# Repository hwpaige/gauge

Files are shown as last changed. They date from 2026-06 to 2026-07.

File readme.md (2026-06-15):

# CHT Gauge

A twin cylinder head temperature (CHT) gauge running on a Banana Pi M4 Zero, displayed on a 1.3" round SPI LCD. Designed to look like a dark-themed aircraft avionics instrument — two filled-arc gauges side by side, one per cylinder, with colour-coded temperature zones and a D-DIN digital readout.

---

## Hardware

| Component | Part |
|---|---|
| SBC | Banana Pi M4 Zero (Allwinner H618, quad-core A53) |
| Display | Pimoroni 1.3" Round SPI Colour LCD (ST7789, 240×240) — PIM570 |
| Thermocouple | MAX31855 or MAX6675 breakout (×2, one per cylinder) |
| OS | Armbian Debian Trixie Minimal |

**Important**: The kernel must provide `/dev/fb0` for the ST7789 (see "Kernel framebuffer driver" below). The Python app no longer drives the display directly.

---

## Wiring

### Display → BPI M4 Zero 40-pin header

The kernel framebuffer overlay (not the Python app) owns the pins. Example mapping used by current overlays/driver code (confirm against your .dts):

| Display Pin | Signal | BPI Header Pin | Notes (Allwinner) |
|---|---|---|---|
| VCC | 3.3V | Pin 1 | |
| GND | GND | Pin 6 | |
| CS | SPI1 CS0 (PH5)  | Pin 24 | |
| SCK | SPI1 SCLK (PH6) | Pin 23 | |
| MOSI | SPI1 MOSI (PH7) | Pin 19 | |
| DC | PI16 | Pin 18 | (offset 272) |
| RST | PC2 | Pin 22 | (offset 66) |
| (BL) | (backlight) | (Pin 35) | Tie to 3.3V (Pin 1) if not software-controlled |

> Backlight: tie BL directly to 3.3V for always-on (recommended for gauge). The kernel panel driver typically handles reset/DC in its DT.

### Thermocouple (MAX31855 / MAX6675) — to be wired

Thermocouples share the SPI bus with the display using separate CS pins. Wiring and sensor code will be added in a future update.

---

## Project Structure

```
cht-gauge/
├── setup.sh          # One-shot bootstrap — run on fresh Armbian flash
├── gauge.py          # Main application (uses kernel /dev/fb0)
├── run.sh            # Launch script
├── test_display.py   # Legacy userspace test (may fail once kernel owns display)
├── pin_test.py       # Dev tool for probing GPIOs/SPI (kernel pins will be busy)
├── driver.py         # Legacy userspace ST7789 driver (kept for reference)
├── .gitignore
└── fonts/
    └── README.md     # Fonts are downloaded by setup.sh, not committed to repo
```

---

## Fresh Install Instructions

### 1. Flash Armbian

Download **Armbian Debian Trixie Minimal** for BPI M4 Zero:
```
https://dl.armbian.com/bananapim4zero/Trixie_current_minimal
```

Flash with [Armbian Imager](https://imager.armbian.com) or Balena Etcher. Pre-configure WiFi credentials in the imager before flashing.

### 2. SSH in

Find the device IP via your router's DHCP client list, then:

```bash
ssh root@<ip-address>
# Default password: 1234 (you'll be prompted to change it)
```

### 3. Run setup

```bash
wget https://raw.githubusercontent.com/hwpaige/gauge/master/setup.sh
bash setup.sh
```

The script will:
- Set the hostname to `moto` (SSH via `root@moto.local` after reboot)
- Enable SPI in `/boot/armbianEnv.txt`
- Install all system and Python dependencies
- Clone this repo to `/root/gauge`
- Download the D-DIN font
- Create a Python virtual environment and install packages
- Prompt to reboot

After reboot, SSH back in with:

```bash
ssh root@moto.local
```

### 4. Test the display

Once the kernel framebuffer driver is active (see below), the display is the system primary framebuffer. A basic test that the fb is working:

```bash
cat /dev/urandom > /dev/fb0   # noise on screen; Ctrl-C to stop
```

Or (inside venv):

```bash
cd /root/gauge
source venv/bin/activate
python3 -c "
import pygame, os
os.environ['SDL_VIDEODRIVER']='fbcon'; os.environ['SDL_FBDEV']='/dev/fb0'
pygame.init()
s = pygame.display.set_mode((240,280))
s.fill((255,0,0)); pygame.display.flip()
input('red fb - press enter'); pygame.quit()
"
```

(If the legacy `test_display.py` using the Python `st7789` package fails with EBUSY, that is expected once the kernel driver owns the pins — it is no longer needed.)

See "Kernel framebuffer driver" section for how the display becomes `/dev/fb0`.

### 5. Run the gauge

```bash
/root/gauge/run.sh
```

(Or manually: `cd /root/gauge && source venv/bin/activate && python3 gauge.py`)

**Important:** Because the kernel is now driving the round display as the primary framebuffer/console, you must run the gauge while on the **actual Linux console** that the display is attached to (not over SSH in most cases).

- Easiest for testing: Plug a USB keyboard into the Banana Pi. The round display should be showing the login prompt. Login directly there as root and run the command on that console.
- SSH sessions often produce `pygame.error: fbcon not available` because the SDL fbcon driver needs a real virtual terminal context.
- For production (recommended): use the included `gauge.service` so it starts automatically on boot and takes over the round display console. No keyboard or SSH run needed after setup.

### Auto-start via systemd (recommended)

From SSH on the Pi:

```bash
cd /root/gauge
git pull   # get the latest gauge.service if you haven't already

sudo cp gauge.service /etc/systemd/system/
sudo systemctl daemon-reload
sudo systemctl enable --now gauge.service

# Optional: stop the default getty so the gauge owns the console cleanly
# (the service tries to chvt to tty1)
sudo systemctl stop getty@tty1.service
sudo systemctl disable getty@tty1.service
```

Check status:

```bash
systemctl status gauge.service
journalctl -u gauge.service -f
```

To stop it temporarily and get a console back:

```bash
sudo systemctl stop gauge.service
sudo chvt 1
# or reboot
```

The service is configured to restart on failure and attaches to the framebuffer console.

See the on-screen error message in the new gauge.py for more details and a quick kernel-fb test command that *does* work over SSH.

---

## Application

`gauge.py` renders two CHT gauges using **pygame** directed at the Linux framebuffer (`/dev/fb0`) via SDL fbcon — no desktop environment required.

The kernel (via a DT overlay for the ST7789 panel, typically exposing `fb_st7789v` or equivalent) must own the display and expose `/dev/fb0` (240×280 logical with the round 240×240 visible area at y=40). The Python code now renders offscreen and writes raw RGB565 frames directly to `/dev/fb0`. This completely avoids SDL's fbcon video driver (which is frequently missing/broken in packaged SDL2 on Armbian) while still benefiting from the kernel's smooth panel handling.

The old userspace Python ST7789 + gpiod + spidev driver path has been removed from the main app (it conflicts with "Device or resource busy" once the kernel claims the pins).

### Gauge design

- **Black background** with slight blue tint
- **270° filled arc** sweep per gauge
- **Colour zones:**
  - Green — 0–60% of range (normal)
  - Amber — 60–85% (caution)
  - Red — 85–100% (danger)
- **Tick marks** — major at 0%, 50%, 100%; minor every 10%
- **Digital readout** in the arc colour at the gauge centre
- **D-DIN font** throughout — industrial/avionics aesthetic
- **Centre divider** with "CYLINDER HEAD TEMP" header

### Temperature ranges

Min/max values are set per-gauge in `gauge.py`:

```python
draw_gauge(screen, LEFT_CENTER,  cht1, 0, 300, "CYL 1", font, small_font)
draw_gauge(screen, RIGHT_CENTER, cht2, 0, 300, "CYL 2", font, small_font)
```

Change `0` and `300` to match your engine's actual operating range.

### Sensor reads

The `read_cht(channel)` function in `gauge.py` currently returns simulated sine-wave values for testing. Replace it with real MAX31855/MAX6675 SPI reads when the thermocouple hardware is wired up.

---

## Dependencies

### System packages

Installed by `setup.sh`:

- `gcc`, `build-essential` — for compiling Python C extensions
- `python3-venv`, `python3-dev`, `python3-pip`
- `git`, `wget`, `unzip`
- `avahi-daemon` — enables `.local` mDNS hostname resolution
- `libsdl2-dev`, `libsdl2-image-dev`, `libsdl2-ttf-dev` — pygame display

### Python packages (runtime)

Installed into `/root/gauge/venv`:

- `pygame` — rendering engine (fbcon targeting kernel `/dev/fb0`)

`st7789`, `pillow`, `spidev`, `gpiod`, `numpy` are also pulled in for the legacy test scripts only.

---

## Kernel framebuffer driver (required)

After the initial `setup.sh` (which only enables spidev), you must make the ST7789 the kernel's primary framebuffer (`/dev/fb0`) so that:

- The kernel owns DC, RST, and the SPI pins (your app will no longer get "Device or resource busy").
- Updates are smooth / tear-free (as you observed after the reboot that made the round display primary).

Typical steps (edit as root):

1. Create a device-tree overlay (example name `st7789-fb.dts`) in `/boot/overlay-user/` (or `/boot/dtb/overlay/` depending on Armbian version). A minimal overlay declares the spi bus + panel compatible (sitronix,st7789v or fbtft), with the correct GPIOs for your board (DC=PI16/272 on pin 18, RST=PC2/66 on pin 22, SPI1 on PH5-8), width/height, and any rotation/x/y offsets the round visible area needs (the gauge code assumes a 240×280 fb with visible content at y=40).

2. Compile it:
   ```
   armbian-add-overlay /boot/overlay-user/st7789-fb.dts
   ```
   (or `dtc -@ -I dts -O dtb -o /boot/dtb/allwinner/overlay/st7789-fb.dtbo ...` and add to user_overlays).

3. Edit `/boot/armbianEnv.txt`:
   ```
   overlays=... spi-spidev   # or remove spidev if the panel driver claims the bus exclusively
   user_overlays=st7789-fb
   # extraargs or param_ lines as required by your overlay (bus num, speed, etc.)
   ```

4. Reboot.

5. Verify:
   ```
   ls -l /dev/fb0
   fbset   # or cat /sys/class/graphics/fb0/virtual_size  (expect something like 240x280)
   ```

Once `/dev/fb0` is the round display, `python3 gauge.py` (or `run.sh`) will use it directly and be super smooth.

If you have a working overlay .dts that matches the Pimoroni 1.3" + BPI M4 Zero pinout (SPI1, offsets 272/66, y_off=40), contribute it!

The gauge code hard-codes the 240×280 / y=40 layout that the kernel driver must expose for the round 240×240 visible panel.

---

## Roadmap

- [ ] Wire and integrate MAX31855 thermocouple reads
- [ ] Add configurable temperature range and alarm thresholds
- [ ] Auto-launch gauge on boot via systemd service
- [ ] Add EGT (exhaust gas temperature) display mode

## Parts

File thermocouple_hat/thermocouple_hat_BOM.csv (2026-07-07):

Designator | Comment | Footprint | Qty
C1,C2,C3,C4,C5,C6,C7,C8,C9,C10,C11,C12,C13,C14 | 100n | Capacitor_SMD:C_0402_1005Metric | 14
D1,D2,D3,D4 | PRTR5V0U2X | Package_TO_SOT_SMD:SOT-143 | 4
J1 | GPIO | Connector_PinSocket_2.54mm:PinSocket_2x20_P2.54mm_Vertical | 1
J2 | Waveshare_1.28in_Touch | Connector_JST:JST_GH_BM13B-GHS-TBT_1x13-1MP_P1.25mm_Vertical | 1
J3 | TC1 | TerminalBlock_Phoenix:TerminalBlock_Phoenix_MPT-0,5-2-2.54_1x02_P2.54mm_Horizontal | 1
J4 | TC2 | TerminalBlock_Phoenix:TerminalBlock_Phoenix_MPT-0,5-2-2.54_1x02_P2.54mm_Horizontal | 1
J5 | TC3 | TerminalBlock_Phoenix:TerminalBlock_Phoenix_MPT-0,5-2-2.54_1x02_P2.54mm_Horizontal | 1
J6 | TC4 | TerminalBlock_Phoenix:TerminalBlock_Phoenix_MPT-0,5-2-2.54_1x02_P2.54mm_Horizontal | 1
LED5 | LED_GREEN | LED_SMD:LED_0603_1608Metric | 1
R1,R2 | 3.9k | Resistor_SMD:R_0402_1005Metric | 2
R3,R4,R17,R18 | 100k | Resistor_SMD:R_0402_1005Metric | 4
R5,R6,R7,R8,R9,R10,R11,R12 | 100 | Resistor_SMD:R_0402_1005Metric | 8
R13,R14,R15,R16 | 10k | Resistor_SMD:R_0402_1005Metric | 4
R23 | 330 | Resistor_SMD:R_0402_1005Metric | 1
R24,R25 | 4.7k | Resistor_SMD:R_0402_1005Metric | 2
U1 | CAT24C256 | Package_SO:SOIC-8_3.9x4.9mm_P1.27mm | 1
U2,U3,U4,U5 | MAX31856 | Package_SO:TSSOP-14_4.4x5mm_P0.65mm | 4
U6 | DS3231MZ | Package_SO:SOIC-8_3.9x4.9mm_P1.27mm | 1

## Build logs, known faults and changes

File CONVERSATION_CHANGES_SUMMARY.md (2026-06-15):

# Banana Pi CHT Gauge - Conversation Changes Summary

**Date**: June 2026 (conversation spanned ~June 14-15)  
**Project**: `gauge` - Twin cylinder head temperature (CHT) gauge on Banana Pi M4 Zero with 1.3" round ST7789 SPI display.  
**Goal of this conversation**: Fix the app after the kernel took over the display as the primary framebuffer.

## Background & Original Problem

- After a reboot, the Banana Pi was using the round display as the **primary display** via the kernel framebuffer driver (`fb_st7789v` or equivalent).
- This produced "super smooth" output with no flickering (the kernel driver handled SPI/panel timing well).
- The existing `gauge.py` (and `driver.py`) used a **userspace ST7789 driver** (`gpiod.request_lines` for DC/RST + `spidev`).
- This caused: `OSError: [Errno 16] Device or resource busy` because the kernel had already claimed the GPIO pins and SPI bus.
- The local workspace had **uncommitted changes** switching to kernel `/dev/fb0` + `pygame` + `fbcon`, but the Pi's `git pull` saw an old version (and later hit an untracked `pin_test.py` conflict).

The root cause: The project had evolved to rely on the **kernel owning the display** for smoothness, but the code and deployment weren't fully updated for that reality.

## Major Architectural Shift

**From**: Userspace pixel pushing (Pygame offscreen → custom ST7789 class → SPI via `spidev` + GPIO via `gpiod`).

**To**: Kernel framebuffer direct write.
- Pygame renders offscreen only (using `SDL_VIDEODRIVER=dummy`).
- At the end of each frame, convert the 240×280 surface to raw **RGB565** bytes.
- Write directly to `/dev/fb0` (via `mmap` for efficiency).
- This lets the **kernel driver** handle all the panel timing, SPI, and refresh — matching the smooth behavior the user observed with the console.

This also eliminated the GPIO "busy" conflict.

## Key Code Changes (gauge.py)

- Removed reliance on `driver.py` / `ST7789` class and `gpiod`/`spidev` for the main app.
- Added `os.environ` setup early (before `import pygame`).
- New helper: `_surface_to_fb565(surface)` — converts Pygame surface to RGB565 bytes.
  - Prefers `numpy` for speed (when available).
  - Pure-Python fallback.
  - Includes **byte swap** to match the format the original userspace driver (and kernel fb) expected:
    ```python
    rgb565 = ((r & 0xF8) << 8) | ((g & 0xFC) << 3) | (b >> 3)
    rgb565 = ((rgb565 >> 8) | ((rgb565 & 0xFF) << 8))  # byte swap
    ```
- Switched to offscreen `full_fb` surface (240×280) + blitting the 240×240 gauge at `y=FB_Y_OFF=40`.
- Direct write path:
  - `open('/dev/fb0', 'r+b')` + `mmap.mmap(...)`
  - `fb_map[:] = buf; fb_map.flush()`
- Added `FBIO_WAITFORVSYNC` ioctl (best-effort) after writes to improve timing and reduce tearing (to better match the kernel console's smoothness).
- **Startup reliability fixes**:
  - Immediate **solid red test pattern** (for 1.5s) on startup for visibility debugging.
  - Explicit first real gauge frame written before the main loop.
  - Prints to journal for diagnostics.
- Debug prints: `SDL_VIDEODRIVER`, framebuffer checks, "First real gauge frame written", etc.
- Graceful cleanup of mmap/fd on exit.
- Event loop (Q to quit) preserved for testing.

## Systemd Service (new file: gauge.service)

- Created `gauge.service` for auto-launch on boot.
- Uses `Environment=SDL_VIDEODRIVER=dummy` + direct `/dev/fb0` write.
- `ExecStartPre` steps:
  - `chvt 1`
  - Disable cursor blink
  - Stop interfering gettys (`getty@tty1`, serial gettys, etc.)
- `Restart=always`, `StandardOutput=journal` / `StandardError=journal` (prevents error text from being painted onto the framebuffer as "terminal" garbage).
- TTY-related options retained for the console context.
- Installation instructions added to README.

High CPU time seen in early journals was from long crash/restart loops on the old fbcon code.

## Documentation & Supporting Files

- **readme.md**:
  - Major rewrite of "Kernel framebuffer driver (required)" section.
  - Updated wiring table (correct BPI M4 Zero pins: SPI1 on PH5–PH8, DC=PI16/pin18, RST=PC2/pin22).
  - New "Auto-start via systemd" subsection with concrete commands.
  - Updated install/test/run instructions (emphasize kernel fb, SSH vs local console).
  - Explained why userspace ST7789 + gpiod/pillow/etc. are now legacy.
- **setup.sh**: Added warnings about needing the kernel ST7789/fb overlay (in addition to spi-spidev). Updated final notes and test instructions.
- **run.sh**: Updated comment to reflect direct fb path.
- **requirements.txt**: Clarified that only `pygame` is runtime-required; others are for legacy tools.
- **test_display.py**: Marked as legacy (will fail with EBUSY once kernel owns pins).
- **pin_test.py**: Committed (was previously untracked in some clones); contains kernel-owned pin warnings.
- Added `CONVERSATION_CHANGES_SUMMARY.md` (this file) for future reference.

## Debugging Journey (Key Failures & Fixes)

1. **EBUSY on gpiod** → Realized kernel now owns display → switched to fb path + pushed commits.
2. **Untracked `pin_test.py` blocking pull** → User `mv` + `git pull`.
3. **`fbcon not available`** (over SSH) → Explained console vs. SSH context. Created systemd service as long-term solution (no keyboard required).
4. **"Only showing in red"** → RGB565 byte order was wrong. Matched original `driver.py` conversion (byte swap).
5. **Blank screen after mmap/vsync** → Vsync ioctl could block before first write. Added:
   - Immediate red test pattern.
   - Explicit first real frame write + prints.
   - Moved vsync *after* write.
6. **High CPU in journal** → Artifact of long restart loop on broken code; fixed by stable direct-write path.

User observation that helped: "When the kernel was the display output, the CLI was super smooth including the blinking cursor (no rapid refresh)." This drove the mmap + vsync improvements to emulate kernel fbcon timing.

## Current Recommended Workflow (as of end of conversation)

1. Kernel DT overlay must expose the round ST7789 as `/dev/fb0` (240×280 logical, visible at y=40).
2. `git pull` on Pi.
3. Install/restart service:
   ```bash
   sudo cp gauge.service /etc/systemd/system/
   sudo systemctl daemon-reload
   sudo systemctl enable --now gauge.service
   # Optional: stop getty
   sudo systemctl stop getty@tty1.service
   sudo systemctl disable getty@tty1.service
   ```
4. Journal for logs: `journalctl -u gauge.service -f`
5. Temporary clean console: `sudo systemctl stop gauge.service && sudo chvt 1`
6. Quick hardware test (works over SSH): `cat /dev/urandom > /dev/fb0` (Ctrl-C after 1-2s). Should show noise if `/dev/fb0` is the round panel.

## Files Changed / Added

- `gauge.py` (major rewrite)
- `gauge.service` (new)
- `readme.md`
- `setup.sh`
- `run.sh`
- `requirements.txt`
- `test_display.py`
- `pin_test.py` (committed)
- `CONVERSATION_CHANGES_SUMMARY.md` (this file)

## Lessons / Future Reference

- When the kernel owns the display as primary fb, **never** use userspace GPIO/SPI drivers for it.
- `fbcon` in SDL2 is fragile on embedded Armbian (especially over SSH or with minimal builds). Direct `/dev/fb0` + mmap is more reliable.
- Match pixel format (RGB565 + byte order) to what the original working driver used.
- Always guarantee at least one visible frame on startup for debugging.
- Use journal logging + test patterns (solid red) when the display can go completely black.
- For maximum smoothness (matching kernel fbcon), combine mmap + `FBIO_WAITFORVSYNC` (or TE pin polling if wired).
- Service + pre-commands to take over the console are essential for "set and forget" embedded gauges.

This summary captures the evolution from a conflicting userspace driver to a robust kernel-fb direct-write solution. Use it when revisiting deployment, debugging color/tearing/blank issues, or extending the project (e.g., adding thermocouple sensors or improving vsync with the TE pin).

---

*Generated at the end of the troubleshooting conversation for future reference.*

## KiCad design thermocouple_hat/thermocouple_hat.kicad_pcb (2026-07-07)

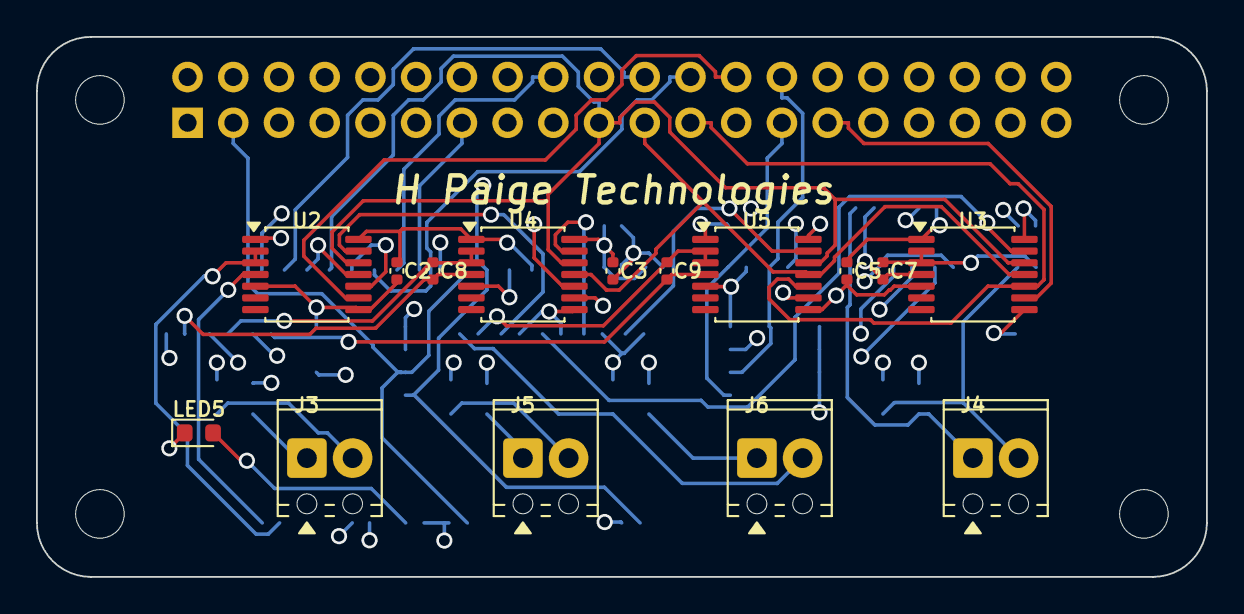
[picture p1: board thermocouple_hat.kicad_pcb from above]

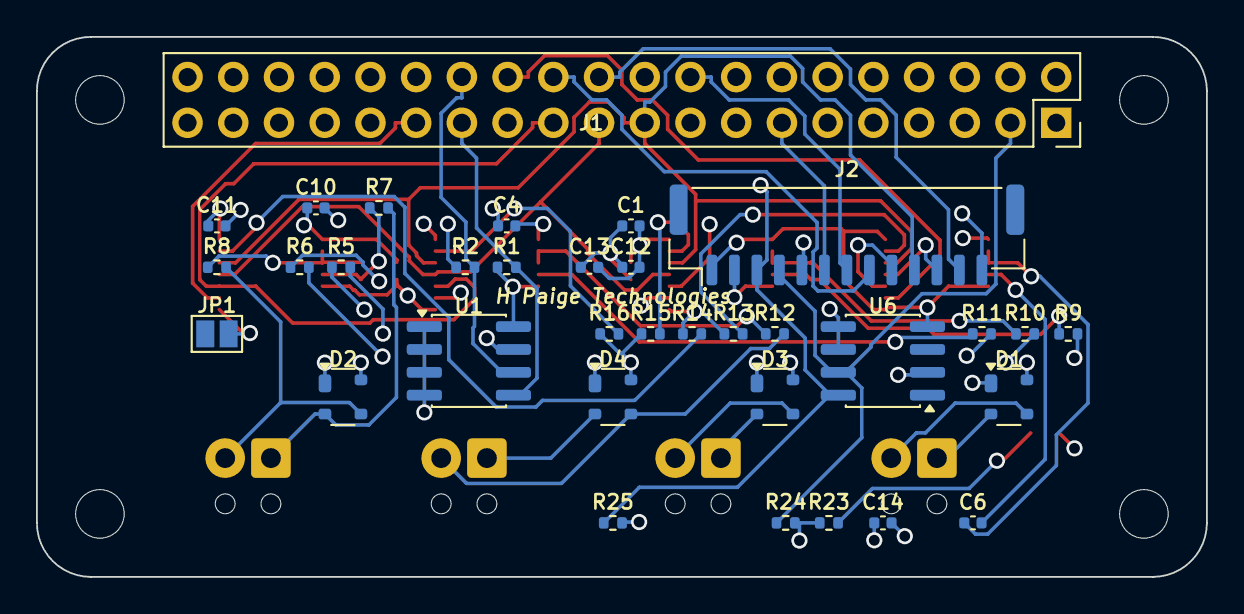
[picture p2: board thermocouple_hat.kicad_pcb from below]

Board: 4 copper layers, 65.0 x 30.0 mm, 53 parts (34 on the bottom side), 41 nets.

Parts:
C1, C2, C3, C4, C5, C6, C7, C8, C9, C10, C11, C12, C13, C14: 100n; C_0402_1005Metric
D1, D2, D3, D4: PRTR5V0U2X; SOT-143
J1: GPIO; PinSocket_2x20_P2.54mm_Vertical
J2: Waveshare_1.28in_Touch; JST_GH_BM13B-GHS-TBT_1x13-1MP_P1.25mm_Vertical
J3: TC1; TerminalBlock_Phoenix_MPT-0,5-2-2.54_1x02_P2.54mm_Horizontal
J4: TC2; TerminalBlock_Phoenix_MPT-0,5-2-2.54_1x02_P2.54mm_Horizontal
J5: TC3; TerminalBlock_Phoenix_MPT-0,5-2-2.54_1x02_P2.54mm_Horizontal
J6: TC4; TerminalBlock_Phoenix_MPT-0,5-2-2.54_1x02_P2.54mm_Horizontal
JP1: ID_WP; SolderJumper-2_P1.3mm_Open_Pad1.0x1.5mm
LED5: LED_GREEN; LED_0603_1608Metric
MH1, MH2, MH3, MH4: MountingHole_2.7mm_M2.5
R1, R2: 3.9k; R_0402_1005Metric
R5, R6, R7, R8, R9, R10, R11, R12: 100; R_0402_1005Metric
R13, R14, R15, R16: 10k; R_0402_1005Metric
R23: 330; R_0402_1005Metric
R24, R25: 4.7k; R_0402_1005Metric
U1: CAT24C256; SOIC-8_3.9x4.9mm_P1.27mm
U2, U3, U4, U5: MAX31856; TSSOP-14_4.4x5mm_P0.65mm
U6: DS3231MZ; SOIC-8_3.9x4.9mm_P1.27mm

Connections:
+3V3: C1.1, C2.1, C3.1, C4.1, C5.1, C10.1, C11.1, C12.1, C13.1, C14.1, D1.4, D2.4, D3.4, D4.4, J1.1, J2.2, JP1.2, R1.1, R2.1, R13.1, R14.1, R15.1, R16.1, R23.1, R24.1, R25.1, U1.8, U2.5, U2.8, U3.5, U3.8, U4.5, U4.8, U5.5, U5.8, U6.2, U6.4
+5V: J1.2, J1.4
DISP_CS: J1.24, J2.8
DISP_DC: J1.18, J2.7
DISP_RST: J1.22, J2.12
GND: C1.2, C2.2, C3.2, C4.2, C5.2, C10.2, C11.2, C12.2, C13.2, C14.2, D1.1, D2.1, D3.1, D4.1, J1.6, J1.9, J1.14, J1.20, J1.25, J1.30, J1.34, J1.39, J2.1, LED5.1, U1.1, U1.2, U1.3, U1.4, U1.7, U2.1, U2.14, U3.1, U3.14, U4.1, U4.14, U5.1, U5.14, U6.5, U6.6
GPIO17: J1.11, J2.5
GPIO26: J1.37, J2.13
GPIO27: J1.13, J2.6
ID_SCL: J1.28, R2.2, U1.6
ID_SDA: J1.27, R1.2, U1.5
PWR_LED_A: LED5.2, R23.2
SCL1: J1.5, J2.3, R25.2, U6.8
SDA1: J1.3, J2.4, R24.2, U6.7
SPI1_MISO: J1.21, J2.11, U2.11, U3.11, U4.11, U5.11
SPI1_MOSI: J1.19, J2.10, U2.12, U3.12, U4.12, U5.12
SPI1_SCK: J1.23, J2.9, U2.10, U3.10, U4.10, U5.10
TC1_CS: J1.26, U2.9
TC1_FAULT_N: R13.2, U2.13
TC1_FT_N: C6.2, R6.1, U2.2, U2.3
TC1_FT_P: C6.1, R5.1, U2.4
TC1_TMINUS: D1.3, J3.2, R6.2
TC1_TPLUS: D1.2, J3.1, R5.2
TC2_CS: J1.29, U3.9
TC2_FAULT_N: R14.2, U3.13
TC2_FT_N: C7.2, R8.1, U3.2, U3.3
TC2_FT_P: C7.1, R7.1, U3.4
TC2_TMINUS: D2.3, J4.2, R8.2
TC2_TPLUS: D2.2, J4.1, R7.2
TC3_CS: J1.31, U4.9
TC3_FAULT_N: R15.2, U4.13
TC3_FT_N: C8.2, R10.1, U4.2, U4.3
TC3_FT_P: C8.1, R9.1, U4.4
TC3_TMINUS: D3.3, J5.2, R10.2
TC3_TPLUS: D3.2, J5.1, R9.2
TC4_CS: J1.32, U5.9
TC4_FAULT_N: R16.2, U5.13
TC4_FT_N: C9.2, R12.1, U5.2, U5.3
TC4_FT_P: C9.1, R11.1, U5.4
TC4_TMINUS: D4.3, J6.2, R12.2
TC4_TPLUS: D4.2, J6.1, R11.2

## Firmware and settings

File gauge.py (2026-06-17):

import os
import struct
import mmap

os.environ.setdefault("SDL_VIDEODRIVER", "dummy")
os.environ.setdefault("SDL_FBDEV", "/dev/fb0")

import pygame
import math
from collections import deque
from datetime import datetime

try:
    import numpy as np
    HAS_NUMPY = True
except ImportError:
    HAS_NUMPY = False


def _surface_to_fb565(surface):
    """Convert a pygame Surface to raw bytes for direct write to /dev/fb0.

    The kernel ST7789/fb driver expects RGB565 in the byte order that the
    original userspace driver (driver.py) used when talking to the controller
    over SPI. We do the same packing here (including the byte swap).
    """
    rgb = pygame.image.tostring(surface, 'RGB')
    if HAS_NUMPY:
        arr = np.frombuffer(rgb, dtype=np.uint8).reshape(-1, 3).astype(np.uint16)
        # Kernel fb_st7789v runs the display in BGR mode, so encode as BGR565.
        # No byte swap — numpy writes uint16 in native LE which is what the kernel expects.
        bgr565 = ((arr[:, 2] & 0xF8) << 8) | ((arr[:, 1] & 0xFC) << 3) | (arr[:, 0] >> 3)
        return bgr565.astype(np.uint16).tobytes()
    else:
        out = bytearray()
        for i in range(0, len(rgb), 3):
            r, g, b = rgb[i], rgb[i + 1], rgb[i + 2]
            out.extend(struct.pack('<H', ((b & 0xf8) << 8) | ((g & 0xfc) << 3) | (r >> 3)))
        return bytes(out)

# ── Config ────────────────────────────────────────────────
SCREEN_W, SCREEN_H = 240, 240
FPS = 30

GAUGE_CENTER = (120, 120)
GAUGE_RADIUS = 118
ARC_WIDTH    = 13

# Left arc  — left side of circle, 105°→255°  (cold=bottom, hot=top)
LEFT_ARC_START  = 105
LEFT_ARC_END    = 255

# Right arc — right side of circle, 75°→-75°  (cold=bottom, hot=top)
RIGHT_ARC_START = 75
RIGHT_ARC_END   = -75

# Colors
BG_COLOR      = (5, 5, 10)
NORMAL_COLOR  = (0, 200, 120)
CAUTION_COLOR = (255, 180, 0)
DANGER_COLOR  = (220, 40, 40)
LABEL_COLOR   = (148, 148, 168)
ZONE_GREEN    = (8, 38, 20)
ZONE_AMBER    = (45, 33, 5)
ZONE_RED      = (48, 10, 10)

# Plot
PLOT_X1   = 55
PLOT_Y1   = 155
PLOT_X2   = 185
PLOT_Y2   = 210
PLOT_LEN  = 130          # samples (one per frame at 2-frame stride = ~8 s)

CYL1_LINE = (0,  210, 130)
CYL2_LINE = (80, 155, 255)

# ── Fonts ─────────────────────────────────────────────────
FONT_DIR      = os.path.join(os.path.dirname(__file__), "fonts")
FALLBACK_FONT = "/usr/share/fonts/truetype/dejavu/DejaVuSans-Bold.ttf"

def find_font(candidates):
    for name in candidates:
        path = os.path.join(FONT_DIR, name)
        if os.path.exists(path):
            return path
    return FALLBACK_FONT

FONT_BOLD      = find_font(["D-DIN-Bold.ttf"])
FONT_REGULAR   = find_font(["D-DIN.ttf"])
FONT_CONDENSED      = find_font(["D-DINCondensed.ttf"])
FONT_CONDENSED_BOLD = find_font(["D-DINCondensed-Bold.ttf"])

# ── Helpers ───────────────────────────────────────────────
def deg_to_rad(deg):
    return math.radians(deg)

def draw_arc(surface, color, center, radius, start_deg, end_deg, width):
    steps = max(180, int(abs(end_deg - start_deg) * 4))
    pts_outer, pts_inner = [], []
    for i in range(steps + 1):
        a = deg_to_rad(start_deg + (end_deg - start_deg) * i / steps)
        pts_outer.append((center[0] + radius           * math.cos(a),
                          center[1] + radius           * math.sin(a)))
        pts_inner.append((center[0] + (radius - width) * math.cos(a),
                          center[1] + (radius - width) * math.sin(a)))
    polygon = pts_outer + list(reversed(pts_inner))
    if len(polygon) > 2:
        pygame.draw.polygon(surface, color, polygon)

def _arc_color(pct):
    if pct < 0.6:    return NORMAL_COLOR
    elif pct < 0.85: return CAUTION_COLOR
    else:            return DANGER_COLOR

def _readout_pos(center, arc_start, arc_end, radius):
    x, y = center
    a = deg_to_rad((arc_start + arc_end) / 2)
    r = radius * 0.55
    return (int(x + r * math.cos(a)), int(y + r * math.sin(a)))

# ── Shape drawing (runs on supersampled surface) ──────────
def draw_gauge_background(surface, center, arc_start, arc_end, radius, arc_width):
    """Static elements: zone bands and tick marks. Pre-render once."""
    x, y  = center
    scale = radius / GAUGE_RADIUS

    p60 = arc_start + 0.60 * (arc_end - arc_start)
    p85 = arc_start + 0.85 * (arc_end - arc_start)
    draw_arc(surface, ZONE_GREEN, center, radius, arc_start, p60,     arc_width)
    draw_arc(surface, ZONE_AMBER, center, radius, p60,       p85,     arc_width)
    draw_arc(surface, ZONE_RED,   center, radius, p85,       arc_end, arc_width)

    outer_r = radius - arc_width - 2 * scale
    for i in range(11):
        ta      = deg_to_rad(arc_start + (i / 10) * (arc_end - arc_start))
        major   = (i % 5 == 0)
        inner_r = outer_r - (9 * scale if major else 4 * scale)
        color   = (170, 170, 185) if major else (60, 60, 75)
        lw      = max(1, round(2 * scale)) if major else max(1, round(scale))
        pygame.draw.line(surface, color,
                         (x + outer_r * math.cos(ta), y + outer_r * math.sin(ta)),
                         (x + inner_r * math.cos(ta), y + inner_r * math.sin(ta)),
                         lw)

def draw_gauge_indicator(surface, center, value, min_val, max_val,
                         arc_start, arc_end, radius, arc_width):
    """Dynamic element: the filled arc showing current value."""
    pct = max(0.0, min(1.0, (value - min_val) / (max_val - min_val)))
    if pct > 0:
        draw_arc(surface, _arc_color(pct), center, radius,
                 arc_start, arc_start + pct * (arc_end - arc_start), arc_width)

# ── Text drawing (runs on native-resolution surface) ──────
def draw_gauge_text(surface, center, value, min_val, max_val,
                    label, font, small_font, arc_start, arc_end):
    pct    = max(0.0, min(1.0, (value - min_val) / (max_val - min_val)))
    rx, ry = _readout_pos(center, arc_start, arc_end, GAUGE_RADIUS)
    col    = _arc_color(pct)

    lbl  = small_font.render(label, True, LABEL_COLOR)
    val  = font.render(str(int(value)), True, col)
    unit = small_font.render("°C", True, LABEL_COLOR)

    surface.blit(lbl,  lbl.get_rect( center=(rx, ry - int(GAUGE_RADIUS * 0.19))))
    surface.blit(val,  val.get_rect( center=(rx, ry + int(GAUGE_RADIUS * 0.02))))
    surface.blit(unit, unit.get_rect(center=(rx, ry + int(GAUGE_RADIUS * 0.21))))

def draw_header(surface, font):
    t = font.render("C H T", True, (118, 118, 138))
    surface.blit(t, t.get_rect(center=(SCREEN_W // 2, SCREEN_H // 16)))

def draw_legend(surface, font, scale=1):
    y       = int((PLOT_Y2 - 5) * scale)
    bar_w   = max(8,  int(10 * scale))
    bar_h   = max(1,  int(2  * scale))
    gap     = max(2,  int(3  * scale))   # bar → label
    spacing = max(4,  int(5  * scale))   # item → item

    lbl1 = font.render("CYL 1", True, LABEL_COLOR)
    lbl2 = font.render("CYL 2", True, LABEL_COLOR)

    item1_w = bar_w + gap + lbl1.get_width()
    item2_w = bar_w + gap + lbl2.get_width()
    x       = SCREEN_W // 2 - (item1_w + spacing + item2_w) // 2

    pygame.draw.rect(surface, CYL1_LINE, (x,                    y - bar_h // 2, bar_w, bar_h))
    surface.blit(lbl1, lbl1.get_rect(midleft=(x + bar_w + gap, y)))

    x2 = x + item1_w + spacing
    pygame.draw.rect(surface, CYL2_LINE, (x2,                   y - bar_h // 2, bar_w, bar_h))
    surface.blit(lbl2, lbl2.get_rect(midleft=(x2 + bar_w + gap, y)))

def draw_time(surface, font):
    surf = font.render(datetime.now().strftime("%H:%M"), True, (255, 255, 255))
    surface.blit(surf, surf.get_rect(center=(SCREEN_W // 2, SCREEN_H - 16)))

def _thick_line(surface, color, pts, width):
    """Draw a filled-polygon ribbon along pts at the given pixel width."""
    if len(pts) < 2:
        return
    upper, lower = [], []
    for i, (x, y) in enumerate(pts):
        if i == 0:
            dx, dy = pts[1][0] - x, pts[1][1] - y
        elif i == len(pts) - 1:
            dx, dy = x - pts[-2][0], y - pts[-2][1]
        else:
            dx, dy = pts[i + 1][0] - pts[i - 1][0], pts[i + 1][1] - pts[i - 1][1]
        ln = math.hypot(dx, dy) or 1.0
        nx, ny = -dy / ln, dx / ln
        hw = width / 2.0
        upper.append((x + nx * hw, y + ny * hw))
        lower.append((x - nx * hw, y - ny * hw))
    polygon = upper + lower[::-1]
    if len(polygon) > 2:
        pygame.draw.polygon(surface, color, polygon)

def _draw_dashed_hline(surface, color, x1, x2, y, dash, gap, thick=1):
    x = x1
    while x < x2:
        pygame.draw.line(surface, color, (x, y), (min(x + dash, x2), y), thick)
        x += dash + gap

def _zone_colors(v, min_val, max_val, normal_line, normal_glow):
    pct = max(0.0, min(1.0, (v - min_val) / (max_val - min_val)))
    if pct < 0.60:   return normal_line, normal_glow
    elif pct < 0.85: return CAUTION_COLOR, (70, 50, 0)
    else:            return DANGER_COLOR,  (70, 12, 12)

def _draw_zone_line(surface, hist, pts, min_val, max_val,
                    normal_line, normal_glow, lw, gw):
    """Draw hist as a thick line. Zone-color changes are prepared but disabled."""
    n = len(pts)
    if n < 2:
        return
    # Uncomment to re-enable zone-aware color changes (green→amber→red):
    # runs = []
    # for i, v in enumerate(hist):
    #     lc, gc = _zone_colors(v, min_val, max_val, normal_line, normal_glow)
    #     if not runs or runs[-1][0] != lc:
    #         runs.append([lc, gc, [i]])
    #     else:
    #         runs[-1][2].append(i)
    # for ri, (lc, gc, idxs) in enumerate(runs):
    #     if ri < len(runs) - 1:
    #         idxs = idxs + [runs[ri + 1][2][0]]
    #     run_pts = [pts[j] for j in idxs]
    #     if len(run_pts) >= 2:
    #         _thick_line(surface, gc, run_pts, gw)
    #         _thick_line(surface, lc, run_pts, lw)
    _thick_line(surface, normal_glow, pts, gw)
    _thick_line(surface, normal_line, pts, lw)


def draw_plot(surface, hist1, hist2, min_val=0, max_val=300, scale=1):
    if len(hist1) < 2:
        return
    x1 = int(PLOT_X1 * scale)
    y1 = int(PLOT_Y1 * scale)
    x2 = int(PLOT_X2 * scale)
    y2 = int(PLOT_Y2 * scale)
    pw, ph = x2 - x1, y2 - y1
    n = len(hist1)

    def make_pts(hist):
        return [
            (x1 + int(i * pw / max(n - 1, 1)),
             y2 - int(max(0.0, min(1.0, (v - min_val) / (max_val - min_val))) * ph))
            for i, v in enumerate(hist)
        ]

    # Faint dashed threshold lines
    dash  = max(3, int(4 * scale))
    gap   = max(2, int(3 * scale))
    thick = max(1, int(scale))
    _draw_dashed_hline(surface, (120, 88,  8), x1, x2, y2 - int(0.60 * ph), dash, gap, thick)
    _draw_dashed_hline(surface, (115, 22, 22), x1, x2, y2 - int(0.85 * ph), dash, gap, thick)

    pts1 = make_pts(hist1)
    pts2 = make_pts(hist2)
    lw   = max(2, round(2.5 * scale))
    gw   = lw * 2

    _draw_zone_line(surface, hist1, pts1, min_val, max_val,
                    CYL1_LINE, (0,  85,  50), lw, gw)
    _draw_zone_line(surface, hist2, pts2, min_val, max_val,
                    CYL2_LINE, (28, 62, 110), lw, gw)

# ── Sensor stub ───────────────────────────────────────────
def read_cht(channel):
    import time
    t = time.time()
    if channel == 0:
        return 150 + 80 * math.sin(t * 0.3)
    else:
        return 120 + 60 * math.sin(t * 0.2 + 1)

# ── Main ──────────────────────────────────────────────────
# Kernel fb_st7789v (or equivalent) driver exposes /dev/fb0 as a 240×280
# framebuffer. The visible round area is 240×240 starting at row 40.
# We render to an offscreen surface and write the raw RGB565 frame directly
# to /dev/fb0. This completely bypasses SDL's fbcon video driver (which is
# frequently not compiled into the packaged SDL2 on these Armbian boards)
# while still getting the smooth, tear-free updates from the kernel driver.
FB_H      = 280
FB_Y_OFF  = 40   # rows of invisible GRAM above the visible panel

def main():
    import time

    pygame.display.init()
    pygame.font.init()

    full_fb    = pygame.Surface((SCREEN_W, FB_H))
    gauge_surf = pygame.Surface((SCREEN_W, SCREEN_H))
    clock      = pygame.time.Clock()

    # ── Display backend selection ──────────────────────────────────────────────
    # Prefer panel-mipi-dbi DRM (card1) for double-buffered vsync page flips.
    # Fall back to /dev/fb0 fbtft mmap if DRM isn't available.
    drm = None
    fb_fd = None
    fb_map = None

    if os.path.exists('/dev/dri/card1'):
        try:
            from drm_flip import DrmFlip
            drm = DrmFlip('/dev/dri/card1')
            print(f"DRM backend: /dev/dri/card1  {drm.width}x{drm.height}")
        except Exception as e:
            print(f"DRM init failed ({e}), falling back to /dev/fb0")
            drm = None

    if drm is None:
        if not os.path.exists('/dev/fb0'):
            print("ERROR: neither /dev/dri/card1 nor /dev/fb0 found.")
            raise SystemExit(1)
        fb_fd  = open('/dev/fb0', 'r+b', buffering=0)
        fb_map = mmap.mmap(fb_fd.fileno(), SCREEN_W * FB_H * 2)
        print("fbdev backend: /dev/fb0")

    def write_frame(buf):
        if drm:
            drm.wait_flip()         # ensure previous SPI transfer is done
            drm.back_buffer[:] = buf
            drm.begin_flip()        # start SPI transfer; rendering continues immediately
        else:
            fb_map[:] = buf

    # Startup visibility test: solid red for 1.5 s
    red_surf = pygame.Surface((SCREEN_W, FB_H))
    red_surf.fill((255, 0, 0))
    write_frame(_surface_to_fb565(red_surf))
    time.sleep(1.5)

    # Now clear to our normal BG and do a full first gauge draw + write
    # before entering the main loop so the real app appears immediately.
    font       = pygame.font.Font(FONT_BOLD,            26)
    small_font = pygame.font.Font(FONT_REGULAR,         12)
    title_font = pygame.font.Font(FONT_CONDENSED,       11)
    time_font  = pygame.font.Font(FONT_CONDENSED_BOLD,  14)

    SSAA  = 2
    ss    = pygame.Surface((SCREEN_W * SSAA, SCREEN_H * SSAA))
    gc_ss = (GAUGE_CENTER[0] * SSAA, GAUGE_CENTER[1] * SSAA)
    gr_ss = GAUGE_RADIUS * SSAA
    aw_ss = ARC_WIDTH    * SSAA

    # Pre-render static elements (zone bands + tick marks) once.
    # These never change at runtime — only the indicator arcs and text change.
    ss_static = pygame.Surface((SCREEN_W * SSAA, SCREEN_H * SSAA))
    ss_static.fill(BG_COLOR)
    draw_gauge_background(ss_static, gc_ss, LEFT_ARC_START,  LEFT_ARC_END,  gr_ss, aw_ss)
    draw_gauge_background(ss_static, gc_ss, RIGHT_ARC_START, RIGHT_ARC_END, gr_ss, aw_ss)

    hist1 = deque([150.0] * PLOT_LEN, maxlen=PLOT_LEN)
    hist2 = deque([150.0] * PLOT_LEN, maxlen=PLOT_LEN)
    frame = 0

    # Do one full draw cycle for the very first real frame (using initial simulated values)
    cht1 = read_cht(0)
    cht2 = read_cht(1)
    ss.blit(ss_static, (0, 0))
    draw_gauge_indicator(ss, gc_ss, cht1, 0, 300, LEFT_ARC_START,  LEFT_ARC_END,  gr_ss, aw_ss)
    draw_gauge_indicator(ss, gc_ss, cht2, 0, 300, RIGHT_ARC_START, RIGHT_ARC_END, gr_ss, aw_ss)
    draw_plot(ss, hist1, hist2, scale=SSAA)
    gauge_surf.blit(pygame.transform.smoothscale(ss, (SCREEN_W, SCREEN_H)), (0, 0))

    draw_header(gauge_surf, title_font)
    draw_gauge_text(gauge_surf, GAUGE_CENTER, cht1, 0, 300, "CYL 1", font, small_font, LEFT_ARC_START,  LEFT_ARC_END)
    draw_gauge_text(gauge_surf, GAUGE_CENTER, cht2, 0, 300, "CYL 2", font, small_font, RIGHT_ARC_START, RIGHT_ARC_END)
    draw_legend(gauge_surf, title_font)
    draw_time(gauge_surf, time_font)

    full_fb.fill(BG_COLOR)
    full_fb.blit(gauge_surf, (0, FB_Y_OFF))
    write_frame(_surface_to_fb565(full_fb))
    print("First real gauge frame written")

    running = True
    while running:
        for event in pygame.event.get():
            if event.type == pygame.QUIT:
                running = False
            if event.type == pygame.KEYDOWN and event.key == pygame.K_q:
                running = False

        cht1 = read_cht(0)
        cht2 = read_cht(1)

        frame += 1
        if frame % 2 == 0:
            hist1.append(cht1)
            hist2.append(cht2)

        ss.blit(ss_static, (0, 0))
        draw_gauge_indicator(ss, gc_ss, cht1, 0, 300, LEFT_ARC_START,  LEFT_ARC_END,  gr_ss, aw_ss)
        draw_gauge_indicator(ss, gc_ss, cht2, 0, 300, RIGHT_ARC_START, RIGHT_ARC_END, gr_ss, aw_ss)
        draw_plot(ss, hist1, hist2, scale=SSAA)
        gauge_surf.blit(pygame.transform.smoothscale(ss, (SCREEN_W, SCREEN_H)), (0, 0))

        draw_header(gauge_surf, title_font)
        draw_gauge_text(gauge_surf, GAUGE_CENTER, cht1, 0, 300, "CYL 1", font, small_font, LEFT_ARC_START,  LEFT_ARC_END)
        draw_gauge_text(gauge_surf, GAUGE_CENTER, cht2, 0, 300, "CYL 2", font, small_font, RIGHT_ARC_START, RIGHT_ARC_END)
        draw_legend(gauge_surf, title_font)
        draw_time(gauge_surf, time_font)

        full_fb.fill(BG_COLOR)
        full_fb.blit(gauge_surf, (0, FB_Y_OFF))
        write_frame(_surface_to_fb565(full_fb))

        if drm is None:
            clock.tick(FPS)     # DRM flip() already rate-limits via vsync wait

    pygame.quit()

    if drm:
        drm.close()
    else:
        try:
            fb_map.close()
            fb_fd.close()
        except Exception:
            pass

if __name__ == "__main__":
    main()

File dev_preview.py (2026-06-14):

"""
dev_preview.py — Windows desktop preview of the CHT gauge UI.

Simulates the 240×240 round ST7789 display at 2× scale with a circular bezel.
Imports gauge.py directly — any change to gauge.py is reflected on next run.

Run:  python dev_preview.py
Keys: Q / Esc   — quit
      Up / Down — scrub CYL 1 temp (manual mode)
      W / S     — scrub CYL 2 temp (manual mode)
      Space     — toggle simulated / manual mode
"""

import pygame
import sys
import os
from collections import deque

sys.path.insert(0, os.path.dirname(__file__))
import gauge as g

# ── Preview config ────────────────────────────────────────
SCALE    = 2
SSAA     = 2

DISPLAY_PX  = g.SCREEN_W * SCALE
SS_PX       = DISPLAY_PX * SSAA
BEZEL_R     = DISPLAY_PX // 2
BEZEL_PAD   = 10            # margin around the gauge circle
WIN_W       = DISPLAY_PX + 2 * BEZEL_PAD
WIN_H       = WIN_W + 22    # extra strip at bottom for HUD text
CX          = WIN_W // 2    # gauge centre in window coords
CY          = WIN_W // 2
GAUGE_BX    = CX - BEZEL_R  # where to blit the 480×480 gauge surface
GAUGE_BY    = CY - BEZEL_R


# ── Helpers ───────────────────────────────────────────────
def make_round_mask(size):
    mask = pygame.Surface((size, size), pygame.SRCALPHA)
    mask.fill((0, 0, 0, 0))
    pygame.draw.circle(mask, (255, 255, 255, 255), (size // 2, size // 2), size // 2)
    return mask

def apply_round_clip(surface, mask):
    result = pygame.Surface(surface.get_size(), pygame.SRCALPHA)
    result.blit(surface, (0, 0))
    result.blit(mask, (0, 0), special_flags=pygame.BLEND_RGBA_MULT)
    return result

def draw_bezel(window, cx, cy):
    pygame.draw.circle(window, (180, 30, 30), (cx, cy), BEZEL_R + 1, 2)

def draw_hud(window, font, mode, cht1, cht2):
    line = (f"{'MANUAL' if mode == 'manual' else 'SIM '}  "
            f"CYL1:{cht1:.0f}°  CYL2:{cht2:.0f}°  "
            f"↑↓ CYL1  W/S CYL2  Space: mode  Q: quit")
    window.blit(font.render(line, True, (60, 60, 78)), (6, WIN_W + 4))

# ── Main ──────────────────────────────────────────────────
def main():
    pygame.init()
    window = pygame.display.set_mode((WIN_W, WIN_H))
    pygame.display.set_caption("CHT Gauge — Dev Preview")
    clock = pygame.time.Clock()

    font       = pygame.font.Font(g.FONT_BOLD,            26 * SCALE)
    small_font = pygame.font.Font(g.FONT_REGULAR,         12 * SCALE)
    title_font = pygame.font.Font(g.FONT_CONDENSED,       11 * SCALE)
    time_font  = pygame.font.Font(g.FONT_CONDENSED_BOLD,  14 * SCALE)
    hud_font   = pygame.font.SysFont("consolas", 11)

    display_surf = pygame.Surface((DISPLAY_PX, DISPLAY_PX))
    ss_surf      = pygame.Surface((SS_PX, SS_PX))
    round_mask   = make_round_mask(DISPLAY_PX)

    gc_display = (g.GAUGE_CENTER[0] * SCALE,        g.GAUGE_CENTER[1] * SCALE)
    gc_ss      = (g.GAUGE_CENTER[0] * SCALE * SSAA, g.GAUGE_CENTER[1] * SCALE * SSAA)
    gr_display = g.GAUGE_RADIUS * SCALE
    gr_ss      = g.GAUGE_RADIUS * SCALE * SSAA
    aw_ss      = g.ARC_WIDTH    * SCALE * SSAA

    hist1 = deque([150.0] * g.PLOT_LEN, maxlen=g.PLOT_LEN)
    hist2 = deque([150.0] * g.PLOT_LEN, maxlen=g.PLOT_LEN)
    frame = 0

    mode = "sim"
    cht1 = 150.0
    cht2 = 120.0
    STEP = 10.0

    running = True
    while running:
        for event in pygame.event.get():
            if event.type == pygame.QUIT:
                running = False
            if event.type == pygame.KEYDOWN:
                if event.key in (pygame.K_q, pygame.K_ESCAPE):
                    running = False
                if event.key == pygame.K_SPACE:
                    mode = "manual" if mode == "sim" else "sim"
                if mode == "manual":
                    if event.key == pygame.K_UP:    cht1 = min(300, cht1 + STEP)
                    if event.key == pygame.K_DOWN:  cht1 = max(0,   cht1 - STEP)
                    if event.key == pygame.K_w:     cht2 = min(300, cht2 + STEP)
                    if event.key == pygame.K_s:     cht2 = max(0,   cht2 - STEP)

        if mode == "sim":
            cht1 = g.read_cht(0)
            cht2 = g.read_cht(1)

        frame += 1
        if frame % 2 == 0:
            hist1.append(cht1)
            hist2.append(cht2)

        # ── 1. Shapes + plot at SS_PX, smoothscale to DISPLAY_PX ─
        ss_surf.fill(g.BG_COLOR)
        g.draw_gauge_shapes(ss_surf, gc_ss, cht1, 0, 300,
                            g.LEFT_ARC_START,  g.LEFT_ARC_END,  gr_ss, aw_ss)
        g.draw_gauge_shapes(ss_surf, gc_ss, cht2, 0, 300,
                            g.RIGHT_ARC_START, g.RIGHT_ARC_END, gr_ss, aw_ss)
        g.draw_plot(ss_surf, hist1, hist2, scale=SCALE * SSAA)
        display_surf.blit(
            pygame.transform.smoothscale(ss_surf, (DISPLAY_PX, DISPLAY_PX)), (0, 0))

        # ── 2. Text at DISPLAY_PX (crisp) ────────────────────────
        g.GAUGE_RADIUS = gr_display
        g.GAUGE_CENTER = gc_display
        g.SCREEN_W     = DISPLAY_PX
        g.SCREEN_H     = DISPLAY_PX

        g.draw_header(display_surf, title_font)
        g.draw_gauge_text(display_surf, gc_display, cht1, 0, 300,
                          "CYL 1", font, small_font, g.LEFT_ARC_START,  g.LEFT_ARC_END)
        g.draw_gauge_text(display_surf, gc_display, cht2, 0, 300,
                          "CYL 2", font, small_font, g.RIGHT_ARC_START, g.RIGHT_ARC_END)
        g.draw_legend(display_surf, title_font, scale=SCALE)
        g.draw_time(display_surf, time_font)

        g.GAUGE_RADIUS = gr_display // SCALE
        g.GAUGE_CENTER = (gc_display[0] // SCALE, gc_display[1] // SCALE)
        g.SCREEN_W     = DISPLAY_PX // SCALE
        g.SCREEN_H     = DISPLAY_PX // SCALE

        # ── 3. Round clip + composite onto window ─────────────────
        clipped = apply_round_clip(display_surf, round_mask)
        window.fill((10, 10, 14))
        draw_bezel(window, CX, CY)
        window.blit(clipped, (GAUGE_BX, GAUGE_BY))
        draw_hud(window, hud_font, mode, cht1, cht2)

        pygame.display.flip()
        clock.tick(g.FPS)

    pygame.quit()

if __name__ == "__main__":
    main()

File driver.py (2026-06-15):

import spidev, time, gpiod, numpy as np
from gpiod.line import Direction, Value

# BPI M4 Zero v2 — Allwinner H618, gpiochip1 = 300b000.pinctrl (288 lines)
# SPI1 bus: PH6=CLK(pin23)  PH7=MOSI(pin19)  PH8=MISO(pin21)  PH5=CS(pin24)
# DC=PI16(272)=pin18  RST=PC2(66)=pin22  (from WiringPi phyToGpio table)
# TE (tearing effect): wire display TE pin to a free header GPIO, pass te=<offset>.
# Hardware CS is kernel-managed — no software CS needed.
_CHIP  = '/dev/gpiochip1'
_CHUNK = 4096


class ST7789:
    def __init__(self, dc, rst, port=1, cs=0,
                 width=240, height=240, speed_hz=16_000_000,
                 x_off=0, y_off=0, te=None):
        self._w, self._h = width, height
        self._x_off, self._y_off = x_off, y_off
        self._dc = dc
        self._te = te

        pin_cfg = {
            dc:  gpiod.LineSettings(direction=Direction.OUTPUT, output_value=Value.ACTIVE),
            rst: gpiod.LineSettings(direction=Direction.OUTPUT, output_value=Value.ACTIVE),
        }
        if te is not None:
            pin_cfg[te] = gpiod.LineSettings(direction=Direction.INPUT)

        self._gpio = gpiod.request_lines(_CHIP, consumer='st7789', config=pin_cfg)

        self._spi = spidev.SpiDev()
        self._spi.open(port, cs)
        self._spi.max_speed_hz = speed_hz
        self._spi.mode = 0

        self._reset(rst)
        self._init()
        if te is not None:
            self._cmd(0x35); self._data(0x00)  # TEON: vsync pulse only
        self._set_window()
        self._clear()
        self._frame_started = False

    def _set_window(self):
        xs, xe = self._x_off, self._x_off + self._w - 1
        ys, ye = self._y_off, self._y_off + self._h - 1
        self._cmd(0x2A); self._data(bytes([xs >> 8, xs & 0xFF, xe >> 8, xe & 0xFF]))
        self._cmd(0x2B); self._data(bytes([ys >> 8, ys & 0xFF, ye >> 8, ye & 0xFF]))

    def _clear(self):
        self._cmd(0x2C)
        self._data(b'\x00\x00' * (self._w * self._h))

    def _set(self, pin, high):
        self._gpio.set_value(pin, Value.ACTIVE if high else Value.INACTIVE)

    def _reset(self, rst):
        self._set(rst, 1); time.sleep(0.05)
        self._set(rst, 0); time.sleep(0.05)
        self._set(rst, 1); time.sleep(0.15)

    def _cmd(self, cmd):
        self._set(self._dc, 0)
        self._spi.writebytes([cmd])

    def _data(self, data):
        self._set(self._dc, 1)
        if isinstance(data, int):
            self._spi.writebytes([data])
        else:
            b = bytes(data) if not isinstance(data, (bytes, bytearray)) else data
            self._spi.writebytes2(b)

    def _init(self):
        self._cmd(0x01); time.sleep(0.15)   # software reset
        self._cmd(0x11); time.sleep(0.12)   # sleep out
        self._cmd(0x3A); self._data(0x05)   # RGB565
        self._cmd(0x36); self._data(0x00)
        self._cmd(0xB2); self._data([0x0C, 0x0C, 0x00, 0x33, 0x33])
        self._cmd(0xB7); self._data(0x35)
        self._cmd(0xBB); self._data(0x28)
        self._cmd(0xC0); self._data(0x0C)
        self._cmd(0xC2); self._data(0x01)
        self._cmd(0xC3); self._data(0x0B)
        self._cmd(0xC4); self._data(0x20)
        self._cmd(0xC6); self._data(0x0F)
        self._cmd(0xD0); self._data([0xA4, 0xA1])
        self._cmd(0xE0); self._data([0xD0,0x01,0x08,0x0F,0x11,0x2A,
                                      0x36,0x55,0x44,0x3A,0x0B,0x06,0x11,0x20])
        self._cmd(0xE1); self._data([0xD0,0x02,0x07,0x0A,0x0B,0x18,
                                      0x34,0x43,0x4A,0x2B,0x1B,0x1C,0x22,0x1F])
        self._cmd(0x21)   # inversion on
        self._cmd(0x13)   # normal display mode
        self._cmd(0x29); time.sleep(0.10)   # display on

    def _wait_te(self):
        # Poll until TE goes LOW (active scan), then HIGH (vblank start).
        # Writing during vblank and staying ahead of the scan line = zero tearing.
        v = self._gpio.get_value
        while v(self._te) == Value.ACTIVE:   # if already HIGH, wait for LOW first
            pass
        while v(self._te) == Value.INACTIVE: # wait for rising edge (vblank start)
            pass

    def display(self, image):
        """Push a 240×240 PIL image (any mode) to the display."""
        # Precompute before touching SPI — no gap between RAMWR and pixel data
        arr = np.frombuffer(image.convert('RGB').tobytes(), dtype=np.uint8)
        arr = arr.reshape(-1, 3).astype(np.uint16)
        rgb565 = ((arr[:,0] & 0xF8) << 8) | ((arr[:,1] & 0xFC) << 3) | (arr[:,2] >> 3)
        buf = ((rgb565 >> 8) | ((rgb565 & 0xFF) << 8)).tobytes()
        if self._te is not None:
            self._wait_te()
        cmd = 0x2C if not self._frame_started else 0x3C
        self._frame_started = True
        self._cmd(cmd)
        self._data(buf)

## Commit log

2026-06-13 Add initial project files for CHT gauge application
    - Create .gitignore to exclude Python artifacts and OS files
    - Add font_readme.md to document font usage
    - Implement gauge.py for rendering CHT gauges using pygame
    - Create run.sh to launch the application on the SPI display
    - Add setup.sh for environment setup and dependencies installation
    - Include test_display.py for verifying SPI display functionality
    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
2026-06-14 Update gauge.py and run.sh for offscreen rendering to SPI display
2026-06-14 Refactor gauge.py to use ST7789 driver and update requirements.txt for dependencies
2026-06-14 Refactor driver.py to use gpiod for GPIO handling and update gauge.py for new pin assignments
2026-06-14 Refactor driver.py to dynamically find GPIO chip and update gauge.py for new pin assignments
2026-06-14 Refactor ST7789 driver in driver.py to include software CS handling and update gauge.py for new pin mapping
2026-06-14 Refactor driver.py to remove manual CS handling in SPI initialization
2026-06-15 Reduce SPI flicker: single writebytes2 call and RAMWRC for subsequent frames
    Replace 4096-byte Python chunk loop with one writebytes2 call per frame to
    eliminate CS toggling mid-transfer. Use RAMWRC (0x3C) after the first frame
    instead of RAMWR (0x2C) to avoid resetting the display address counter on
    every update.
    [driver.py, gauge.py]
2026-06-15 Switch gauge.py to kernel fbcon /dev/fb0 rendering (fixes GPIO EBUSY after kernel driver claims display)
    - Use SDL fbcon + /dev/fb0 provided by fb_st7789v (or equiv)
    - Render 240x240 gauge into 240x280 fb at y-offset 40
    - No more userspace ST7789/gpiod/spidev for main app => no resource busy
    - Matches observed 'super smooth no flickering' behavior
    - Old offscreen + disp.display() path removed
    [gauge.py]
2026-06-15 Docs + scripts: document kernel fb requirement, fix EBUSY root cause, update wiring/install notes, mark legacy tools
    - README now explains why kernel /dev/fb0 is mandatory for smooth operation and to avoid GPIO busy
    - setup.sh warns + notes about the extra overlay step needed
    - requirements / run.sh / test_display updated with context
    - Wiring table corrected toward actual BPI pinouts used by the drivers
    [test_display.py]
2026-06-15 Add pin_test.py (dev GPIO/SPI probe tool, with kernel-owned pin warnings)
2026-06-15 Improve fbcon initialization: set SDL env vars before importing pygame, add diagnostics, and a clear user-friendly error + instructions when 'fbcon not available' happens over SSH
    [gauge.py]
2026-06-15 Add gauge.service systemd unit for auto-start on the kernel framebuffer console at boot
2026-06-15 Make error handling cleaner (no traceback spam), switch service logging to journal to avoid polluting the fb with error text, improve takeover pre-commands
    [gauge.py]
2026-06-15 Switch to direct /dev/fb0 raw RGB565 write (bypasses SDL fbcon entirely). Use dummy SDL driver + offscreen rendering + direct device write for reliable kernel fb output. Simplify service accordingly.
2026-06-15 Fix red-only display: byte-swap the RGB565 conversion to match the order the original ST7789 driver used (and what the kernel fb expects for this panel).
    [gauge.py]
2026-06-15 Use mmap + FBIO_WAITFORVSYNC for direct fb writes. This should get much closer to the smooth kernel console behavior the user observed (vs tearing from raw write() every frame).
2026-06-15 Guarantee first frame is written before any vsync wait. Move vsync after the write so the initial paint always happens (prevents 'nothing on screen' if ioctl blocks on first call).
    [gauge.py]
2026-06-15 Add immediate solid red test frame + explicit first real gauge frame write with prints. This will show on screen whether writes are reaching the panel at all, and guarantee the app is visible right a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
2026-06-15 Fix service ExecStartPre quoting and suppress ALSA underruns
    Split multiline ExecStartPre shell block into separate directives —
    systemd was dropping the whole block due to unbalanced quotes, so chvt
    and getty stop were silently not running.
    Replace pygame.init() with display+font-only init to stop the audio
    mixer from starting (was causing ALSA underrun noise in the journal).
    [gauge.py]
2026-06-15 Fix pixel encoding: BGR565 not RGB565 for kernel fb_st7789v
    The kernel driver initialises the ST7789 in BGR mode, so bits[15:11]
    are B and bits[4:0] are R. Writing RGB565 caused R/B channel swap
    (red appeared blue). Switch to BGR565 and drop the now-wrong byte swap
    — numpy uint16 is naturally little-endian which is what the kernel
    framebuffer expects.
    [gauge.py]
2026-06-15 Lower frame rate to 10fps, remove dead vsync ioctl
    fbtft does not implement FBIO_WAITFORVSYNC (confirmed ENOTTY). At 30fps,
    Python mmap writes race with the kernel's deferred_io SPI push (~16ms at
    64MHz), causing visible tearing on every frame. At 10fps the kernel push
    completes ~33ms after our write, well before the next 100ms frame — no
    collision, no tearing.
    [gauge.py]
2026-06-15 Pre-render static gauge elements, remove mmap.flush(), raise fps to 30
    mmap.flush() calls msync(MS_SYNC) which blocks until the 16ms SPI transfer
    completes on every frame — cut from 20ms to 0.04ms by removing it. The fbtft
    deferred_io page-fault mechanism still triggers the kernel push asynchronously.
    Zone bands and tick marks are static and now pre-rendered once at startup on
    ss_static. Each frame only draws the 2 dynamic indicator arcs + plot. Total
    frame budget drops from ~49ms to ~13ms, allowing 30fps with headroom to spare.
2026-06-15 Add panel-mipi-dbi DRM backend with double-buffered vsync page flips
    drm_flip.py: Python ctypes wrapper for DRM dumb-buffer page flips.
    DrmFlip.flip() blocks until the kernel signals the flip-complete event,
    which fires after the SPI transfer finishes. This eliminates the
    Python-write vs kernel-SPI-read race that caused tearing with fbtft.
    gauge.py: auto-detects /dev/dri/card1 (panel-mipi-dbi) at startup and
    uses DrmFlip if available, falling back to the /dev/fb0 fbtft path.
    DRM mode removes the clock.tick() rate limit since vsync wait naturally
    paces the loop to the display refresh rate.
    Companion changes on board (not in git):
    /lib/firmware/panel-mipi-dbi.bin ST7789 init sequence bina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
    [drm_flip.py, gauge.py]
2026-06-16 Fix ST7789 overlay: add PIO fragment to mux PH5 as SPI1_CS0
    Without this the CS pin stays unclaimed in pinmux, so the SPI
    controller never asserts chip-select and the display ignores all data.
    Adds fragment@0 targeting &pio to activate the spi1 function on PH5,
    and wires it via pinctrl-1 on the spi1 node.
2026-06-17 Add panel-mipi-dbi DRM overlay for tear-free double-buffered display
    Replaces fbtft/fb0 with the panel-mipi-dbi DRM driver which creates
    /dev/dri/card1 and supports double-buffered page-flip vsync via KMS.
    This eliminates the tearing race that fbtft deferred_io has at 64 MHz
    SPI vs ~60 Hz panel scan rate.
    - overlays/panel-mipi-dbi-st7789.dts: new DT overlay; keeps the PH5
    CS-pinmux fix from st7789v.dts, uses panel-timing 240x280 with all
    porches zero (top_offset=0, full GRAM range 0-279).
    - overlays/gen_panel_firmware.py: generates the 41-byte firmware file
    /lib/firmware/panel-mipi-dbi-spi.bin with ST7789 init sequence
    (SWRESET, SLPOUT, COLMOD=0x55, MADCTL=0x08 BGR, INVON, DISPON).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
2026-06-17 Fix panel-mipi-dbi overlay: add missing width-mm and height-mm
    of_get_drm_panel_display_mode() requires width-mm and height-mm on the
    device node (not inside panel-timing). Without them it returns -EINVAL
    (-22) and the driver fails to probe.
2026-06-17 Fix EFAULT in drm_flip.py: allocate encoder/props arrays for DRM ioctls
    Second DRM_IOCTL_MODE_GETRESOURCES call had count_encoders=1 but
    encoder_id_ptr=NULL → kernel EFAULT. Second GETCONNECTOR call similarly
    missing encoders/props/prop_values arrays.
    [drm_flip.py]
2026-06-17 Pipeline DRM flips: overlap rendering with SPI transfer for ~33fps
    Previously write_frame called flip() which blocked for ~30ms (SPI
    transfer) before rendering the next frame, giving ~23fps.
    Split into begin_flip() (non-blocking submit) + wait_flip() (barrier
    before next write). Now rendering happens concurrently with the SPI
    push: frame time = max(render_time, spi_time) = ~30ms → ~33fps.
    [drm_flip.py, gauge.py]
2026-07-07 Add framebuffer test scripts for color writing and diagnostics
2026-07-07 Add KiCad project files and local history documentation
    [thermocouple_hat.dsn, thermocouple_hat.kicad_pcb, thermocouple_hat.kicad_sch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]
2026-07-07 Interactive TUI + GitHub-clone setup for the thermocouple tester
    thermocouple_test.py: menu-driven curses UI — monitor all 4 channels,
    focus a single channel with a large readout, one-shot probe, and live
    settings (thermocouple type / units / poll rate / mains filter).
    Keeps --plain/--once/--selftest/--sim for scripting.
    setup_pi.sh: bootstrap from GitHub — clone/pull the repo to ~/gauge (or use
    a local checkout in place), install python3-spidev + python3-lgpio, enable
    SPI0 with spi0-1cs (frees GPIO7 for TC1's software CS), reboot if needed,
    then self-test, probe, and launch the UI.
    [thermocouple_test.py]
